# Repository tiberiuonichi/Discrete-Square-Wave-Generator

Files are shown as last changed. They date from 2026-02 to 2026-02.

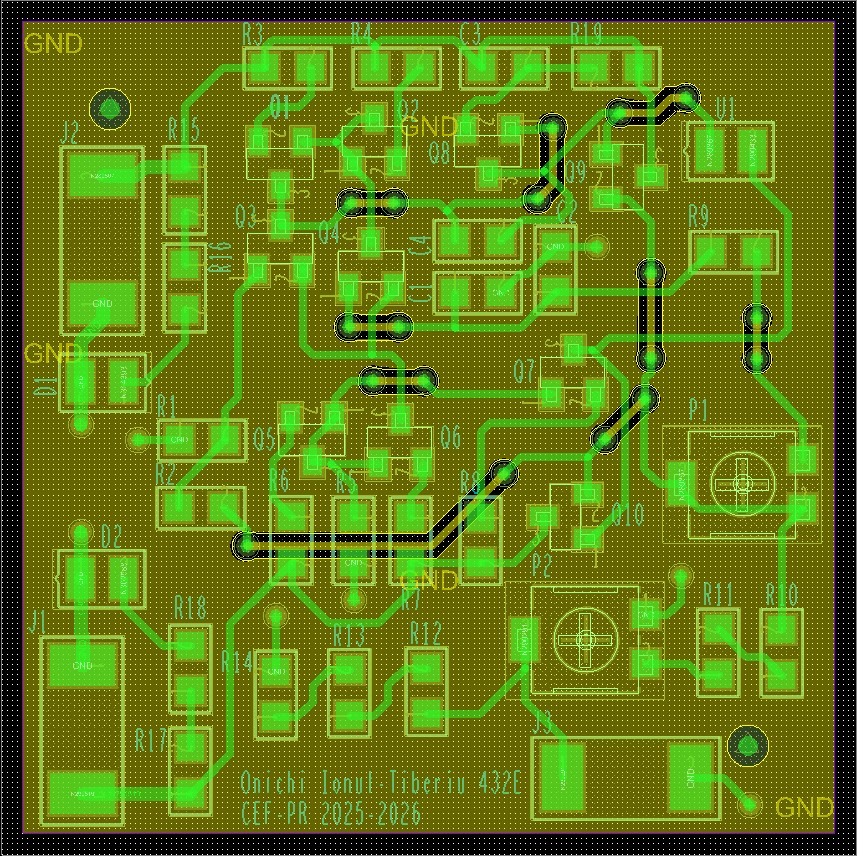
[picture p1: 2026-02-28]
Layout/LAYOUT.jpg

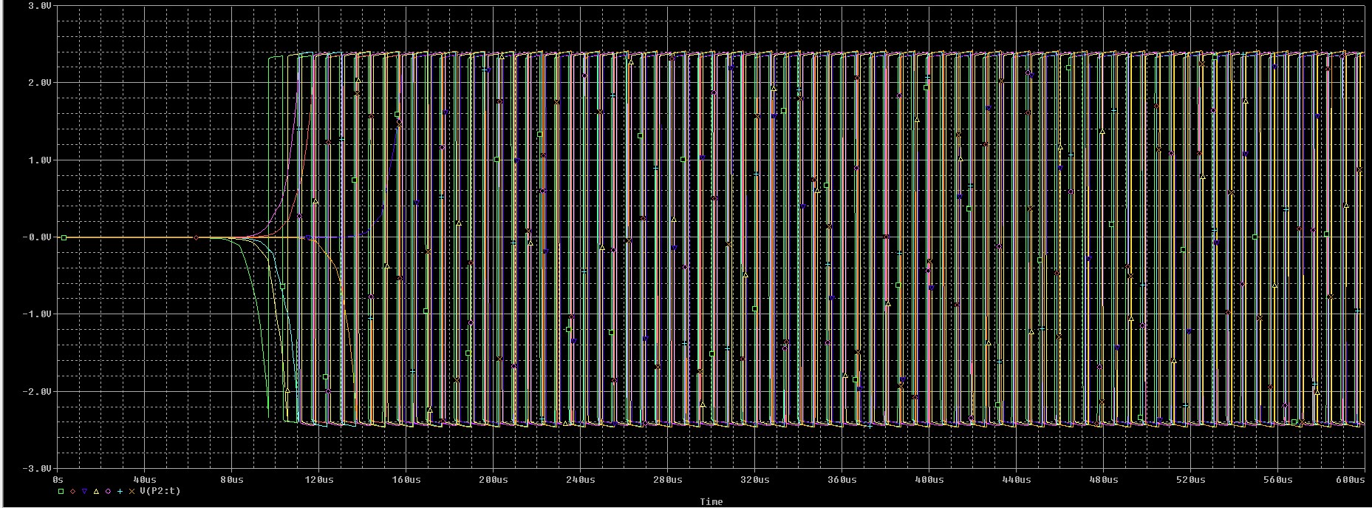
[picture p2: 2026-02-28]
Simulation/Thermal_Analysis_Sweep.jpg

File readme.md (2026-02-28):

# Discrete Transistor-Level Square Wave Generator

## Project Description
This project focuses on the design, simulation, and physical layout of a relaxation oscillator configured as a square wave generator. The core of the circuit is a Schmitt Trigger implemented through a custom-designed Operational Amplifier (Op-Amp) built entirely from discrete bipolar junction transistors (BJT). 

The implementation demonstrates a deep understanding of analog integrated circuit architecture, featuring a multi-stage amplifier design rather than relying on off-the-shelf integrated circuits. The project was developed using the Cadence OrCAD suite, including Capture for schematics, PSpice for analog analysis, and PCB Editor for the physical board design.

The design includes a complete manufacturing package (Drill Charts, Solder Mask, and Silk Screen layers) optimized for SMD assembly.

## Technical Specifications
- Topology: Relaxation Oscillator using a Discrete Op-Amp Schmitt Trigger
- Frequency Range: Adjustable from 38 kHz to 76 kHz
- Output Voltage (Vpp): 0 V to 4.75 V
- Load Impedance (RL): 19 kΩ
- Power Supply: Dual Rail ±9V DC
- Technology: Surface Mount Devices (SMD) and Through-Hole (THT) components

## Circuit Architecture
The discrete operational amplifier is composed of several fundamental stages:
1. Input Stage: Differential pair utilizing Q3 and Q4 (QBC846B) with an active load current mirror (Q1, Q2) to maximize open-loop gain and CMRR.
2. Intermediate Gain Stage: High-gain common emitter amplifier (Q8).
3. Output Stage: Complementary push-pull configuration (Q9, Q10) providing low output impedance and sufficient current drive for the feedback network.
4. Bias Circuitry: Transistor-based current sources (Q5, Q6) to ensure stable operating points across the entire operating range.

## Simulation and Performance Analysis
Extensive PSpice simulations were performed to validate the design across various conditions:
- Transient Analysis: Verification of the RC time constants and the switching thresholds.
- Power Analysis: Calculation of static and dynamic power dissipation to ensure thermal stability (Power_Dissipation_Map).
- Parametric Sweeps: Evaluation of the output frequency and amplitude stability relative to component tolerances.
- Bias Point Analysis: Validation of the DC operating points for all discrete stages (DC_Voltage_Bias_Points and DC_Current_Bias_Points).

## Project Structure
- /Design_Files: OrCAD Capture source files (.DSN, .OPJ).
- /Simulation: PSpice simulation profiles, waveforms, and analysis results.
- /Layout: PCB design files including the board file (.BRD) and manufacturing data.
- /BOM: Detailed Bill of Materials including manufacturer part numbers.
- /Docs: Technical reports, block diagrams, and manufacturing tables.
- /Datasheets: Technical specifications for the discrete components used in the design.

## Visual Documentation
The following results were captured during the PSpice simulation phase:
- Output Waveforms: [Maximum Peak-to-Peak Voltage](Simulation/Maximum_Peak-to-Peak_Voltage.jpg), [Minimum Peak-to-Peak Voltage](Simulation/Minimum_Peak-to-Peak_Voltage.jpg).
- Analysis: [Thermal_Analysis_Sweep](Simulation/Thermal_Analysis_Sweep.jpg), [Power Dissipation Map](Simulation/Power_Dissipation_Map.jpg).
- DC Verification: [Voltage Bias Points](Simulation/DC_Voltage_Bias_Points.jpg), [Current Bias Points](Simulation/DC_Current_Bias_Points.jpg).

## Documentation
The detailed technical report, including analytical calculations for the Op-Amp stages and PSpice simulation results, is available in the following document:
- [Technical_Report_RO.pdf](Docs/Technical_Report_RO.pdf) (Language: Romanian)

---
- **Author:** Onichi Ionut-Tiberiu
- **Tools:** OrCAD, GitHub Desktop.

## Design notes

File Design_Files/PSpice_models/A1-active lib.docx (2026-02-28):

77 | 4148 | (LINK) (http://www.tme.eu/ro/details/1n4148-0805/diode-universale-smd/dc-components/cd4148ws0805c/) | 1N4148-0805
79 | 2.7V | (LINK) (http://www.tme.eu/ro/details/bzx84c2v7/diode-zener-smd/on-semiconductor/bzx84c2v7lt1g/) | BZX84C2V7
80 | 5.1V | (LINK) (http://www.tme.eu/ro/details/bzx84c5v1/diode-zener-smd/nxp/bzx84-c5v1215/) | BZX84C5V1
81 | 5.6V | (LINK) (http://www.tme.eu/ro/details/bzx84c5v6/diode-zener-smd/nxp/bzx84-c5v6215/) | BZX84C5V6
82 | 6.2V | (LINK) (http://www.tme.eu/ro/details/bzx84c6v2/diode-zener-smd/nxp/bzx84-c6v2215/) | BZX84C6V2
83 | 6.8V | (LINK) (http://www.tme.eu/ro/details/bzx84c6v8/diode-zener-smd/nxp/bzx84-c6v8215/) | BZX84C6V8
84 | 8.2V | (LINK) (http://www.tme.eu/ro/details/bzx84c8v2/diode-zener-smd/nxp/bzx84-c8v2215/) | BZX84C8V2
85 | 10V | (LINK) (http://www.tme.eu/ro/details/bzx84c10/diode-zener-smd/nxp/bzx84-c10215/) | BZX84C10
86 | PNP | (LINK) (http://www.tme.eu/ro/details/bc856b.215/tranzistori-smd-pnp/nxp/) | BC856B
87 | NPN | (LINK) (http://www.tme.eu/ro/details/bc846b.215/tranzistori-smd-npn/nxp/) | BC846B
89 | N-JFET | (LINK) (http://www.tme.eu/ro/details/mmbfj309lt1g/tranzistori-canal-n-smd/on-semiconductor/) | MMBFJ309LT1G
90 | P-JFET | (LINK) (http://www.tme.eu/ro/details/mmbfj177lt1g/tranzistori-canal-p-smd/on-semiconductor/) | MMBFJ177LT1G
91 | NPN | (LINK) (http://www.tme.eu/ro/details/bc817-25-dio/tranzistori-smd-npn/diotec-semiconductor/bc817-25/) | BC817-25-DIO
93 | PNP | (LINK) (http://www.tme.eu/ro/details/bc807-25-dio/tranzistori-smd-pnp/diotec-semiconductor/bc807-25/) | BC807-25-DIO
94 | NPN | (LINK) (http://www.tme.eu/ro/details/mjd31cg/tranzistori-smd-npn/on-semiconductor/) | MJD31CG
96 | PNP | (LINK) (http://www.tme.eu/ro/details/mjd32cg/tranzistori-smd-pnp/on-semiconductor/) | MJD32CG
97 | Nmos | (LINK) (http://www.tme.eu/ro/details/irfr120npbf/tranzistori-canal-n-smd/international-rectifier/) | IRFR120NPBF

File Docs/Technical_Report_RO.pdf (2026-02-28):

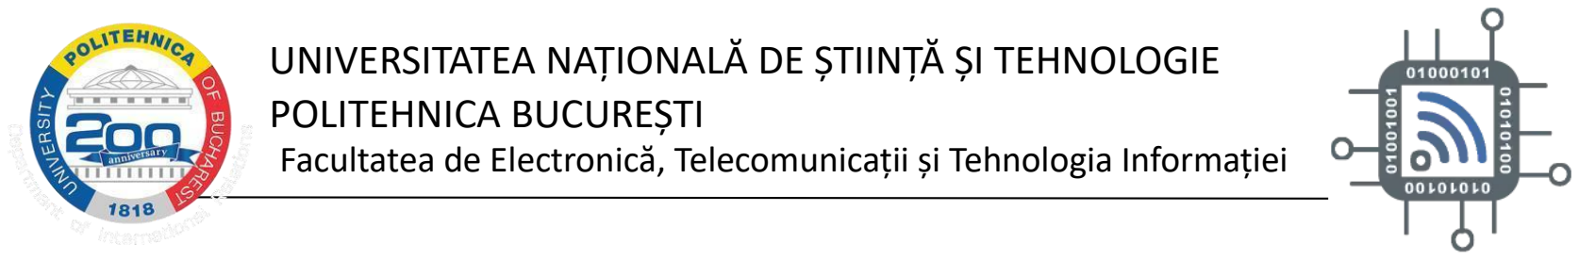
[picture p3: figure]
POLITEHNICA BUCUREȘTI

## Proiect 1 – Dispozitive și circuite electronice

## Generator de semnal dreptunghiular

### Student: Onichi Ionuț-Tiberiu Grupa: 432E

### Profesori coordonatori: Conf. Dr. Ing. Drăghici Florin Ș.l. Dr. Ing. Pantazică Mihaela

## UNIVERSITATEA NAȚIONALĂ DE ȘTIINȚĂ ȘI TEHNOLOGIE

### Facultatea de Electronică, Telecomunicații și Tehnologia Informației

# Cuprins

# 1. Date inițiale de proiectare

## 1.1. Tema proiectului

### Să se proiecteze și realizeze un generator de semnal dreptunghiular cu următoarele caracteristici:

- Frecvența de oscilație, f0, reglabilă în intervalul 38-76 KHz;
- Factor de umplere: 0.5;
- Sarcina la ieșire, RL: 19kΩ;
- Valoarea (vârf la vârf) a oscilației la ieșire, Vo, reglabilă în intervalul 0-4.75V;
- Semnalul la ieșire nu are componentă continuă;

### - Domeniul temperaturilor de funcționare: 0° - 70°C (verificabil prin testare în

temperatură);
- Semnalizarea prezenței tensiunilor de intrare/ieșire cu o diodă de tip LED.

## 1.2. Schema bloc a montajului electric

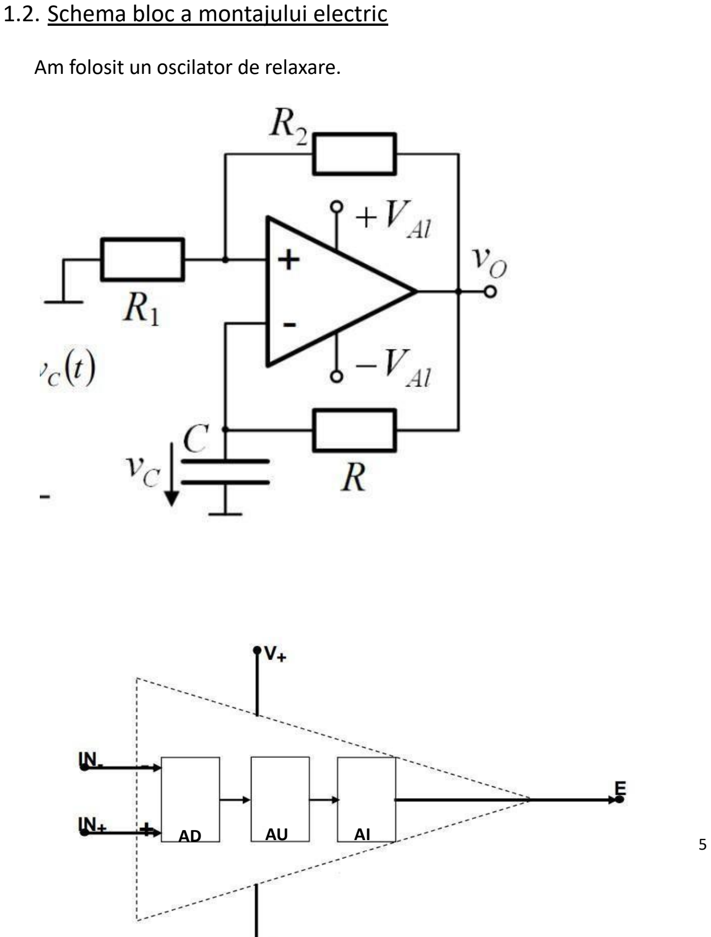
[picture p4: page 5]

AD | AU | AI

Am folosit un oscilator de relaxare.

## 1.3. Schema electrică a montajului electric

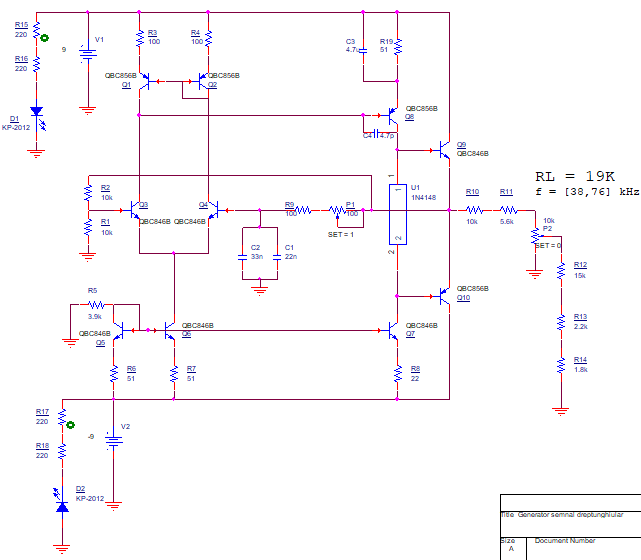
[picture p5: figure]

# 2. Conținut tehnic/științific al proiectului

## 2.1. Descrierea funcțională a circuitului

### Am construit un oscilator de relaxare dintr-un comparator inversor cu histerezis și

o rețea RC pe intrarea inversoare.

### Intrarea neinversoare este conectată la divizorul de tensiune format din R1 și R2, prin intermediul căruia de aplică o parte din semnalul de la ieșire și prin care se fixează

tensiunile de prag de histerezis.

Gruparea formată din C1, C2, R9 și P1 setează frecvența de oscilație.

### Amplificatorul operațional folosit este unul standard, format din 3 etaje de amplificare:

### - etaj de amplificare diferențială

### - etaj de amplificare în tensiune

- etaj de amplificare în curent.
Am folosit două surse de alimentare de ±9V.

### 2.1.1. Etajul diferențial

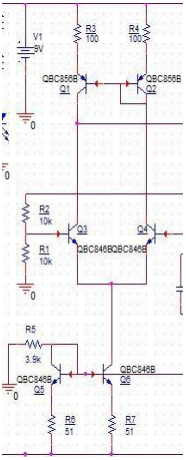
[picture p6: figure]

### Etajul are rolul de a realiza conversia dintre o tensiune de

intrare și o mărime de ieșire exprimată drept curent,

### comportându-se ca un bloc de transconductanță. Cu ajutorul impedanței de intrare foarte mari, acesta poate face cu legătura între sursa de semnal și etajele următoare ale

amplificatorului operațional.

### Structura principală este alcătuită din tranzistoarele NPN Q3 și Q4, tip BC846B, care primesc direct semnalele aplicate la

intrările amplificatorului operațional.

### Pentru a crește câștigul, a îmbunătăți stabilitatea funcționării și a limita nivelul de zgomot, sunt integrate două subetaje

suplimentare: o oglindă de curent și o sursă de curent.

### Tranzistoarele PNP Q1 și Q2, de tip BC856B, sunt utilizate pentru a asigura egalitatea curenților de colector ai

tranzistoarelor care formează etajul diferențial principal.

### Polarizarea elementelor active este furnizată de o sursă de curent realizată cu Q5, Q6 și rezistorul R9. Această configurație generează un curent de referință de 2.11 mA, necesar pentru

formarea unui semnal dreptunghiular bine proporționat.

### 2.1.2. Etajul de amplificare în tensiune

### În acest caz am utilizat un etaj de transimpedanță, conceput să

convertească curentul de la intrare într-o tensiune ridicată la ieșire.

### Datorită amplificării mari în regim de buclă deschisă, am folosit o reacție negativă pentru a stabiliza și ajusta tensiunea la valoarea

cerută în specificațiile inițiale.

### În acest etaj intervin două condensatoare cu roluri specifice:

### Condensatorul de 4.7 pF funcționează ca un condensator Miller, fiind responsabil pentru compensarea în frecvență. Reduce câștigul la

frecvențe înalte și asigură stabilitatea buclei de reacție.

Condensatorul de 4.7 µF are rol de filtrare și decuplare a alimentării.

### Acesta stabilizează tensiunea din nodul respective și reduce zgomotul provenit din alimentare, contribuind la funcționarea stabilă a sursei

de curent.

### Amplificarea propriu-zisă este realizată de tranzistorul PNP Q7, model BC856B, configurat în emitor comun, ceea ce îi conferă un câștig ridicat. Acesta asigură reglarea tensiunii la nivelul dorit și are ca element de sarcină o sursă de curent bazată pe tranzistorul

Q8.

### Sursa de curent stabilește curentul care alimentează etajul final, determinând

astfel funcționarea corectă a întregului ansamblu.

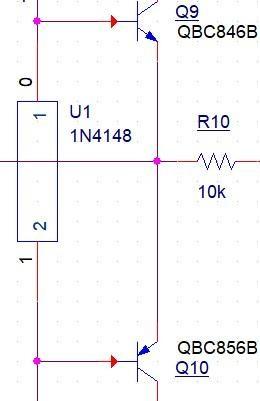
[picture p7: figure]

### 2.1.3. Etajul de amplificare în curent

### Acest etaj are o amplificare unitară a tensiunii stabilite în etajul anterior, motiv pentru care este

utilizată o conexiune de tip colector comun. Tranzistoarele vor disipa o putere semnificativă, datorită curentului care va trece și prin sarcină.

### Configurate push-pull, cele două tranzistoare funcționează ca un etaj final de clasă B: Q9 gestionează alternanțele pozitive, iar Q10 pe cele

negative.

### Dioda 1N4148 asigură polarizarea corectă bază– emitor pentru ambele tranzistoare, reducând zona

moartă și distorsiunile.

### 2.1.4. LED

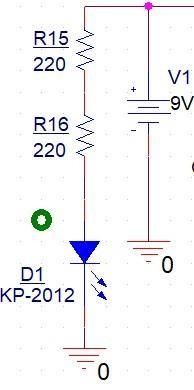
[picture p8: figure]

### Conform cerințelor am semnalizat tensiunile de intrare/iesire în circuit printr-un led de tip KP2012SRC-PRV, în serie cu rezistența R15/ R17 și

R16/R18.

### Luând în considerare puterea maximă admisă pe rezistente (125mW), pe LED(100mW) și valoarea tensiunii de funcționare uzuală pentru acesta (aproximativ 2.2V), precum și curentul necesar pentru aprindere [1 – 30 mA], am ales valoarea

de 220Ω pentru rezistențe.

## 2.2. Calcul de dimensionare

### 2.2.1. Frecvența de oscilație & factorul de umplere

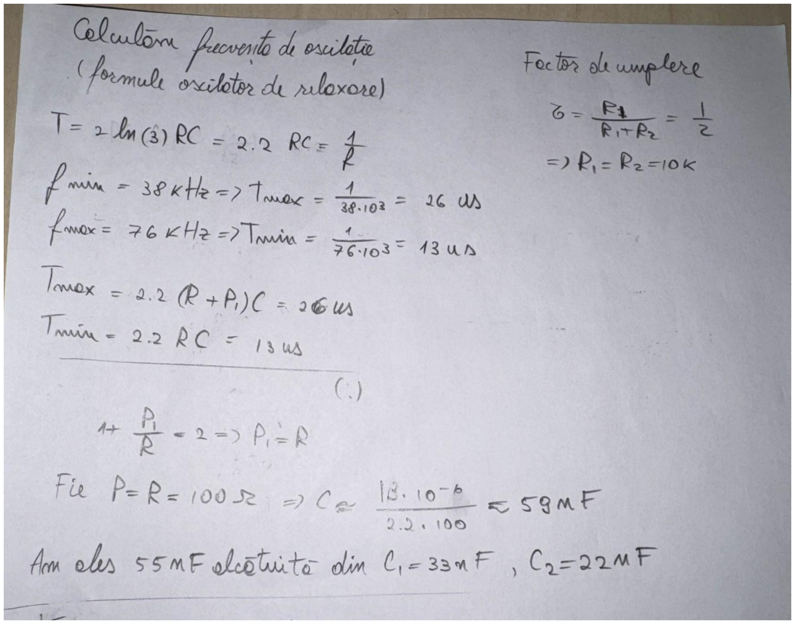
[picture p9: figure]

### 2.2.2. Tensiunea vârf la vârf

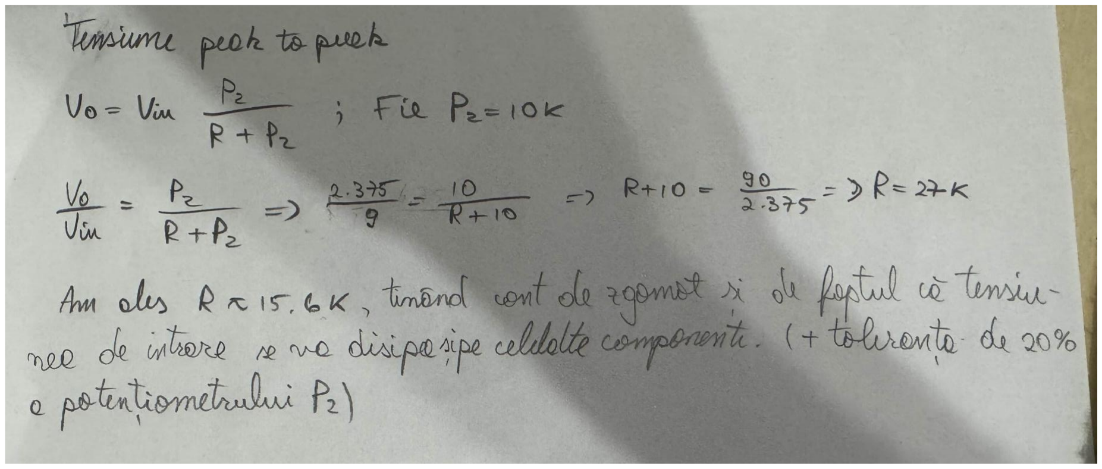
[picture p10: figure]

## 2.3. Punctul static de funcționare

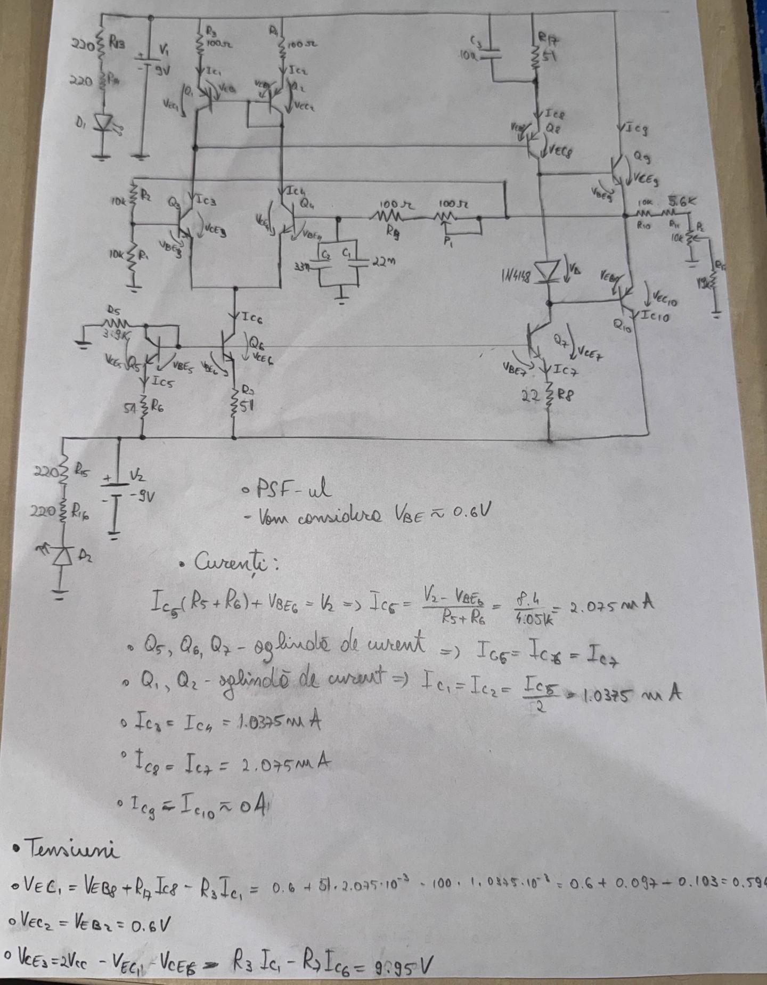
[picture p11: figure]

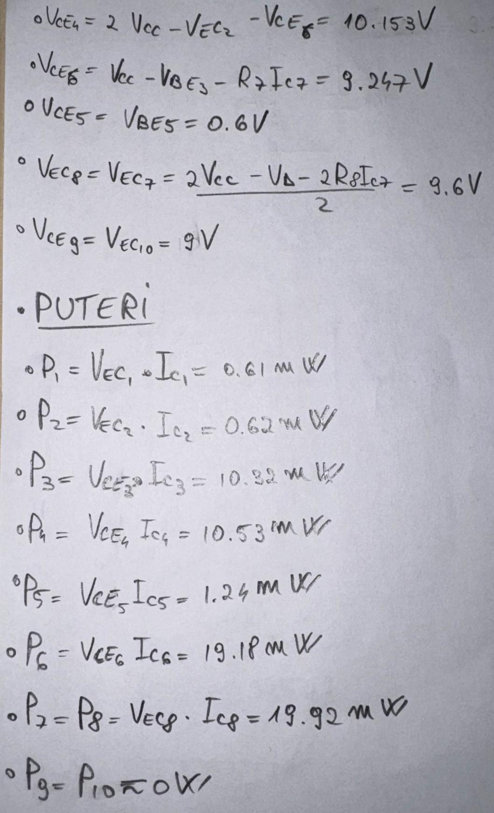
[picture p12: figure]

# 3. Simularea montajului electric

## 3.1. Curenți

### Verificând foile de catalog ale componentelor, acestea merg în regulă la curenții

obținuți.

## 3.2. Tensiuni

### Verificând foile de catalog ale componentelor, acestea merg în regulă pentru

tensiunile obținute.

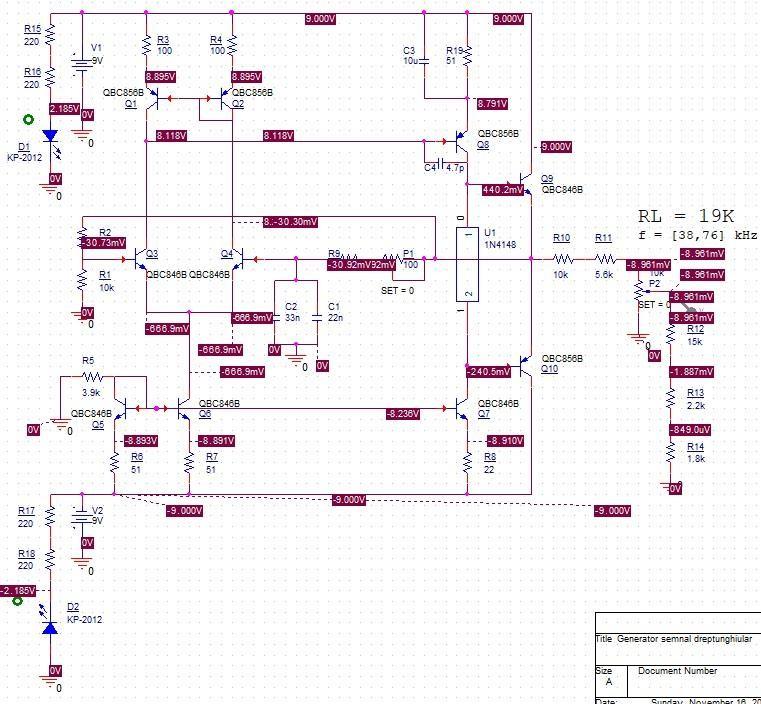
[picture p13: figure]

## 3.3. Puteri

### De asemenea, și puterile se încadrează în parametrii normali de funcționare a

componentelor.

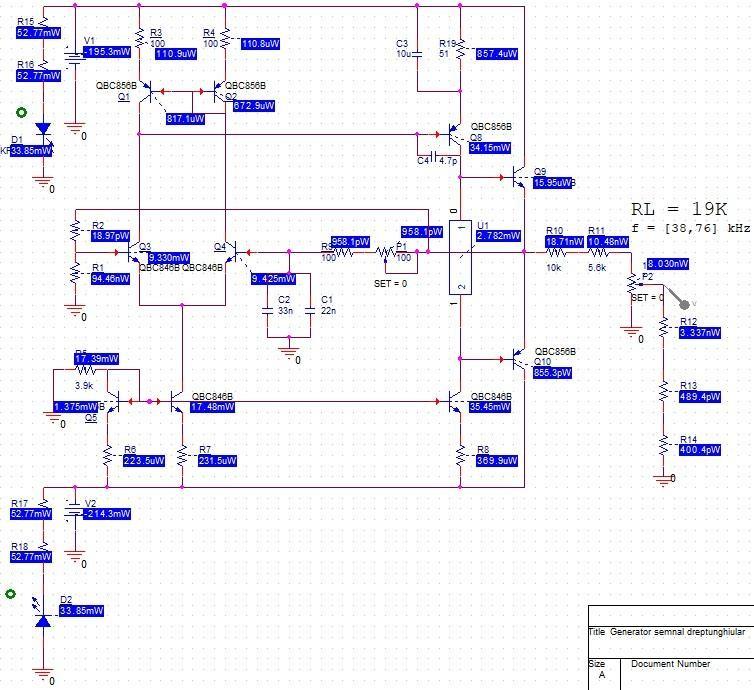
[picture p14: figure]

3.4. P1 = 0, P2 = 0Ω.

### Pentru aceste valori se obțin:

- fmin= 38.77kHz;
- VPP= 4.78V;
- Componenta continuă este neglijabilă.

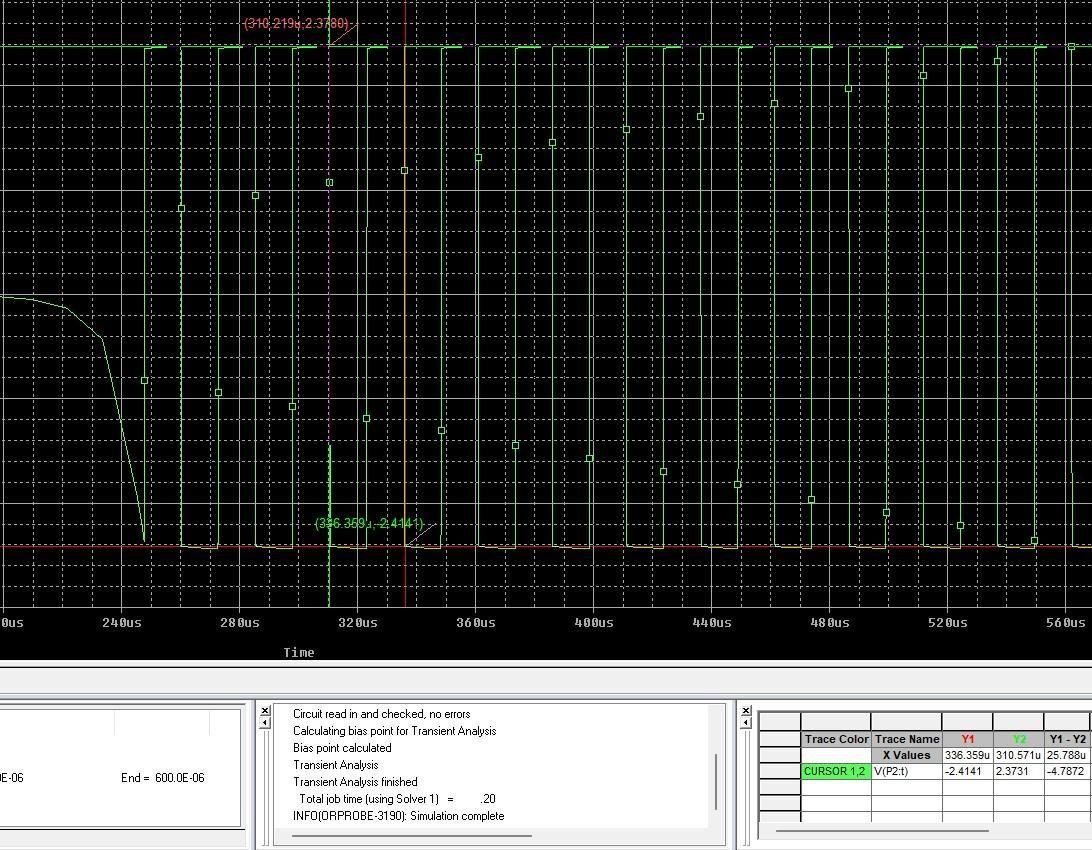
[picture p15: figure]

3.5. P1 = 100Ω, P2 = 0Ω.

### Pentru aceste valori se obțin:

- fmax= 77.5kHz;
- VPP= 4.74V;
- Componenta continuă este neglijabilă.

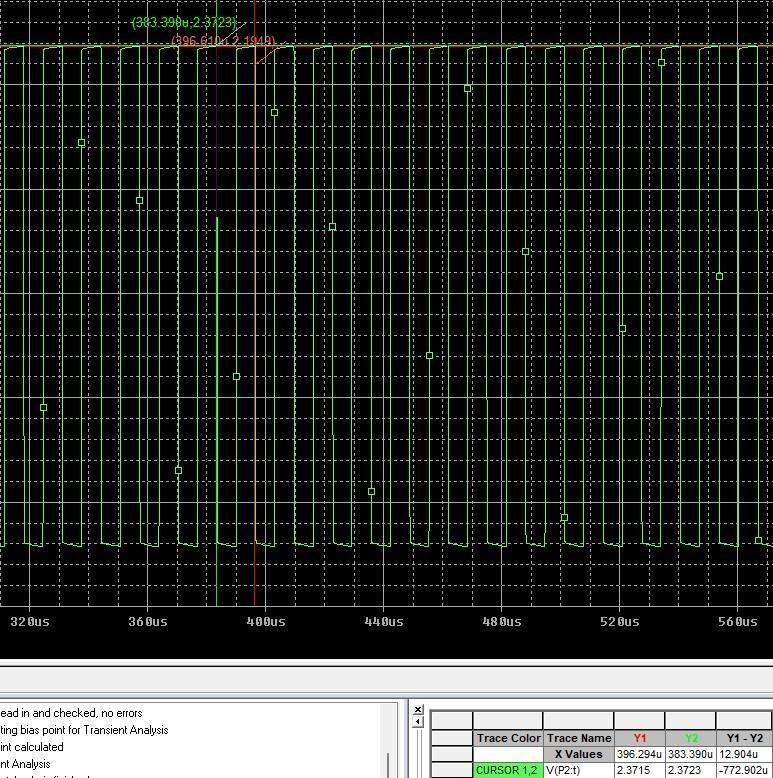
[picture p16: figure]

## 3.6. P1=100Ω & P1=0, P2=10k

### Pentru aceste valori se obțin:

- fmax= 77.6kHz & fmin= 38.8kHz;
- VPP= 631nV;

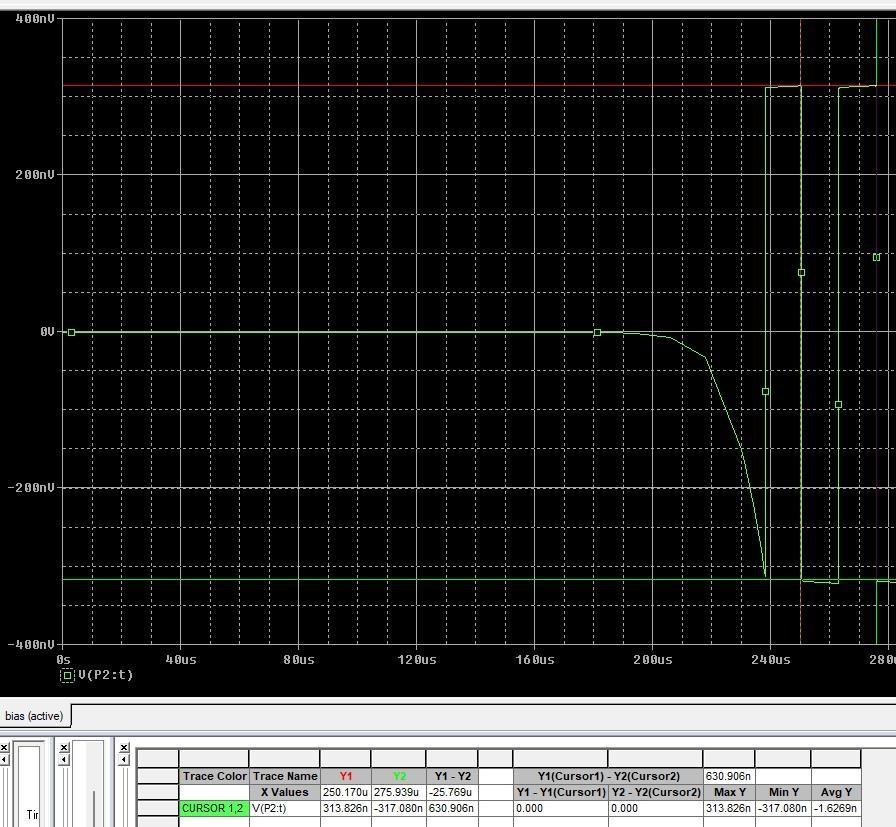
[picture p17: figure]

## 3.7. Temperatură

### Am simulat funcționarea circuitului la -20°, 0°, 25°, 50°, 75°, 100°, 120°C, toate

componentele funcționând normal în tot intervalul de temperatură.

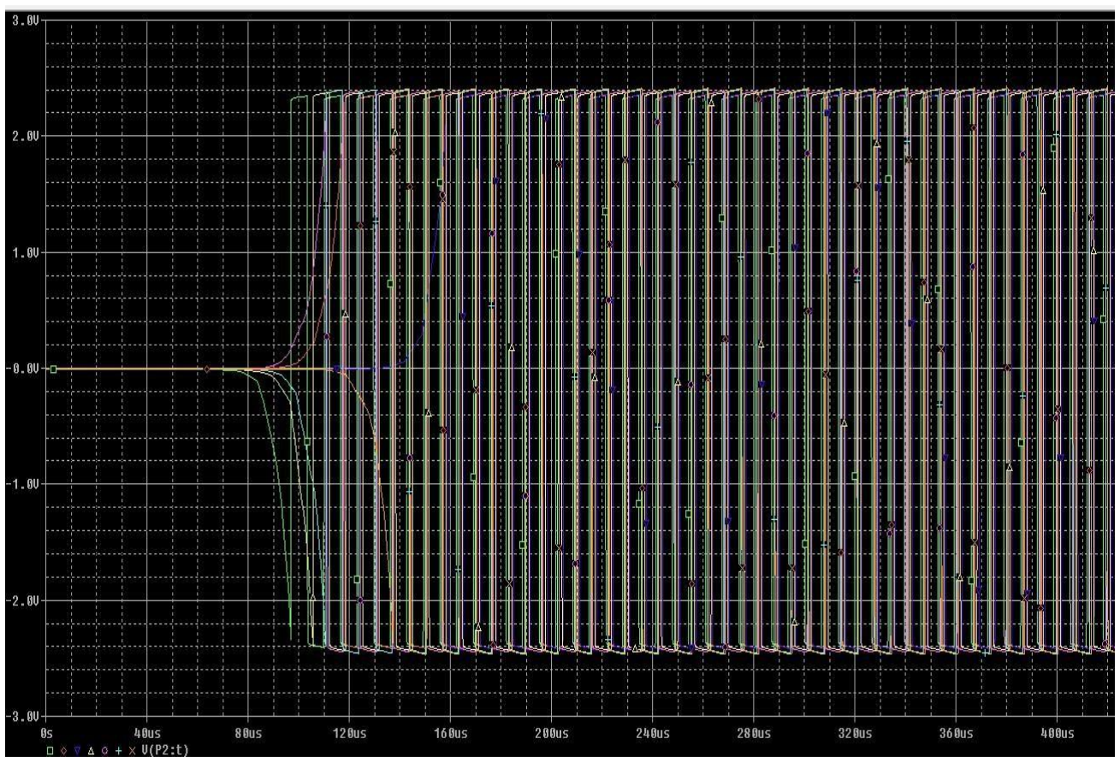
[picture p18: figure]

# 4.Layout

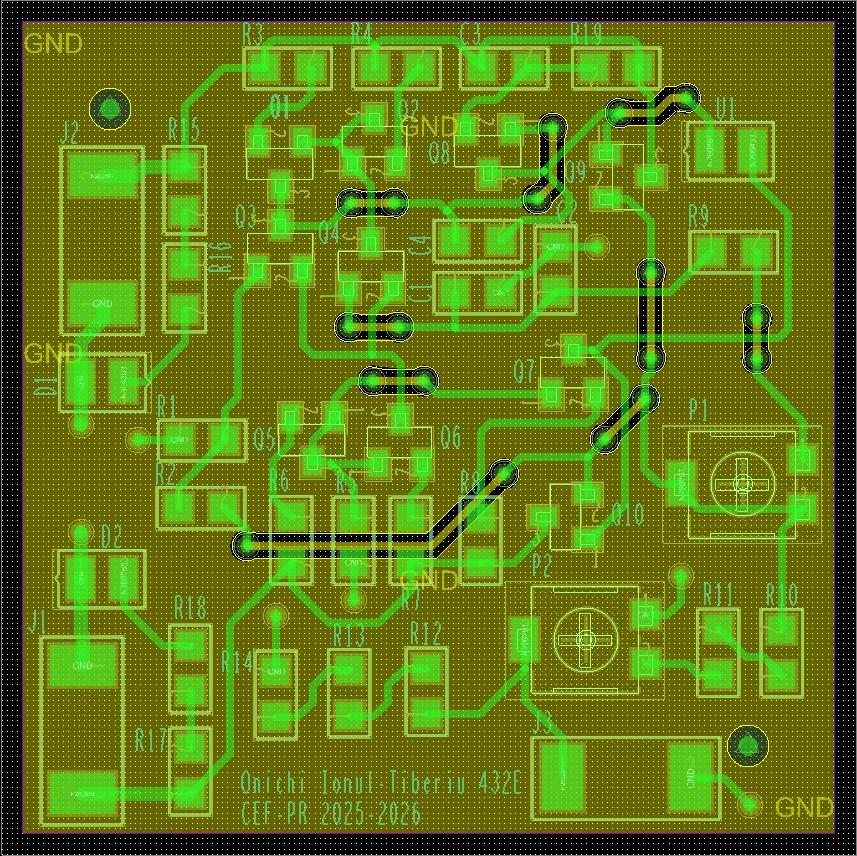
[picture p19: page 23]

### 4.1. PCB DESIGN

## 4.2. BOARD OUTLINE

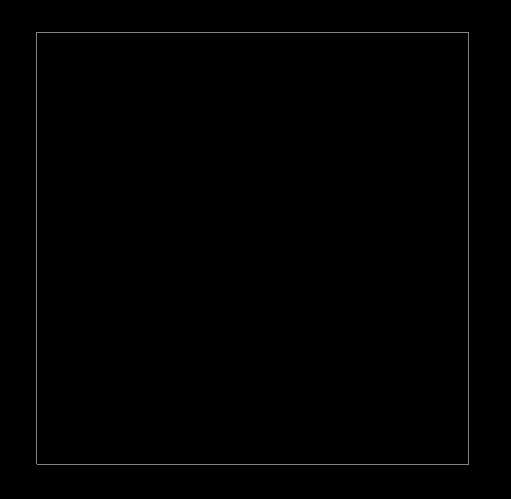
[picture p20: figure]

## 4.3. BOTTOM

## 4.4. FABRICATION

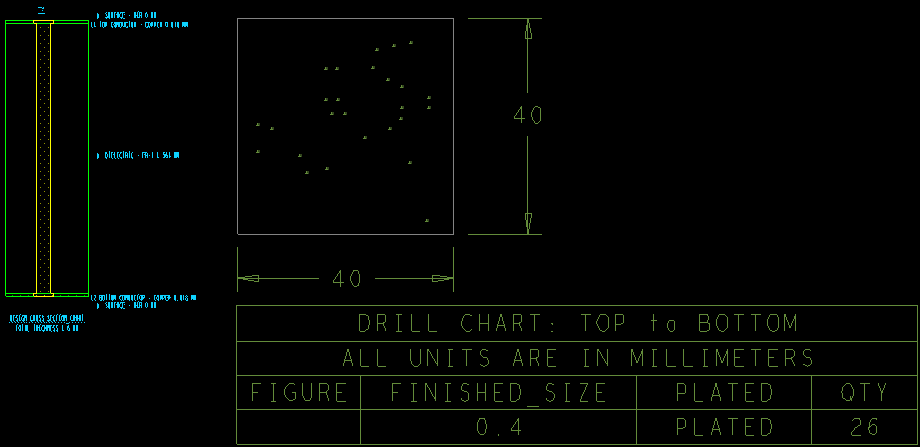
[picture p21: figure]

## 4.5. SOLDERMASK BOTTOM

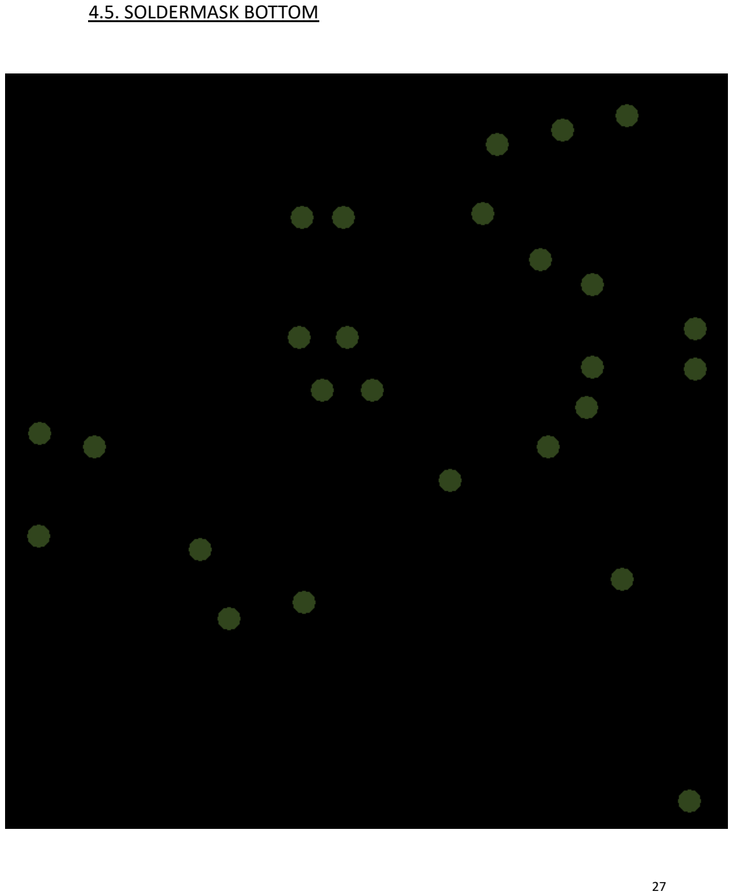
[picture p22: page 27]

## 4.6. SOLDERMASK TOP

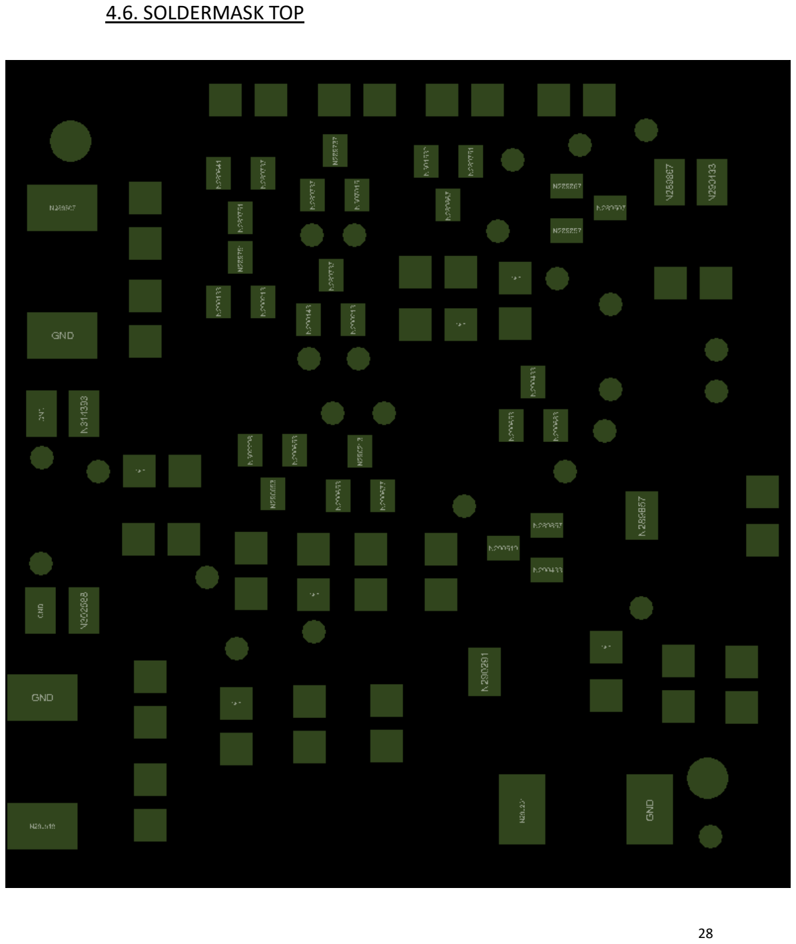
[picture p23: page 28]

## 4.7. SOLDERPASTE TOP

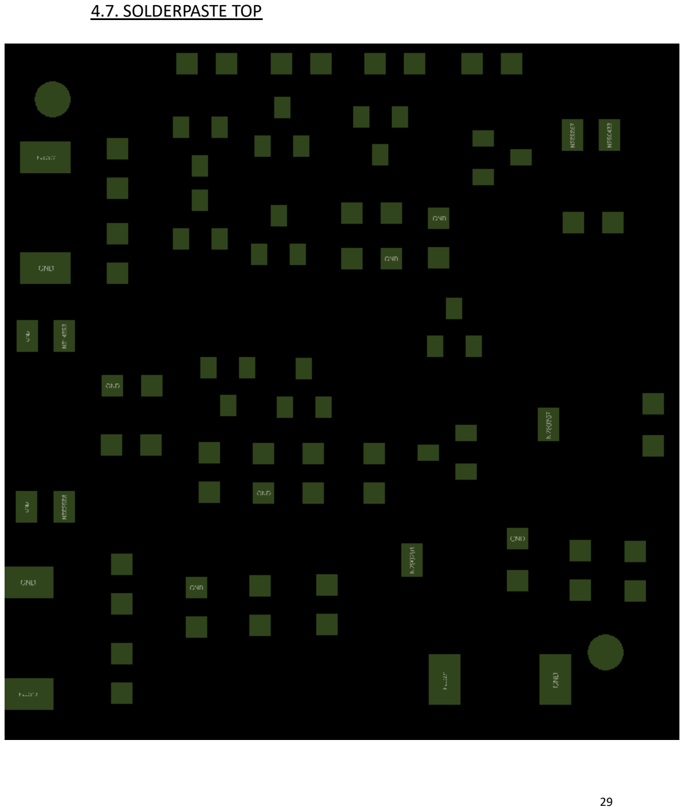
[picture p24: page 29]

## 4.8. SILKSCREEN TOP

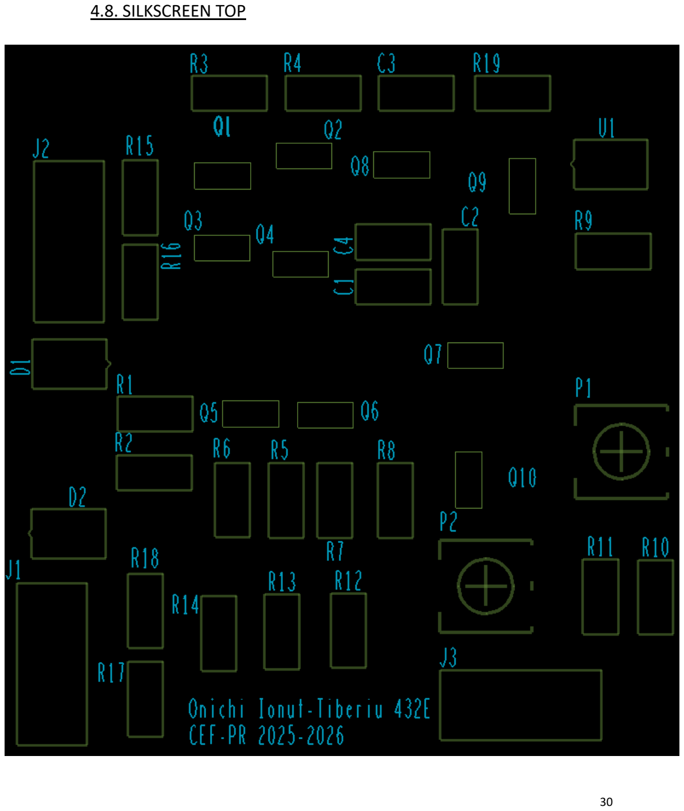
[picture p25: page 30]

## 4.9. LAYER TOP

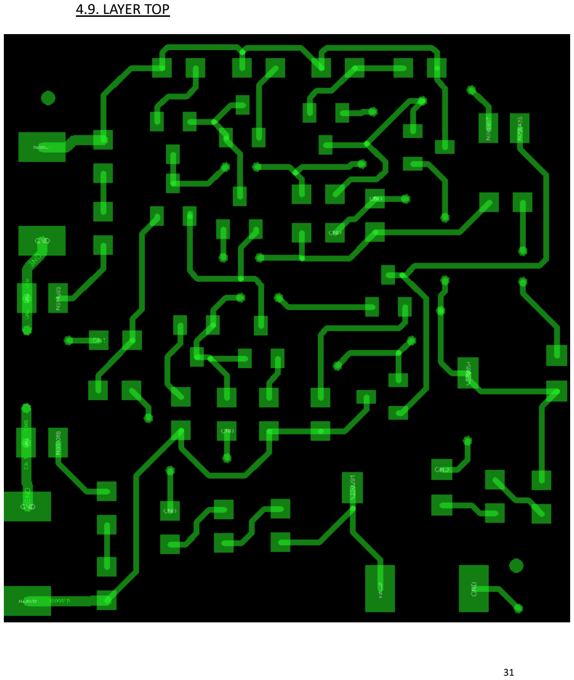
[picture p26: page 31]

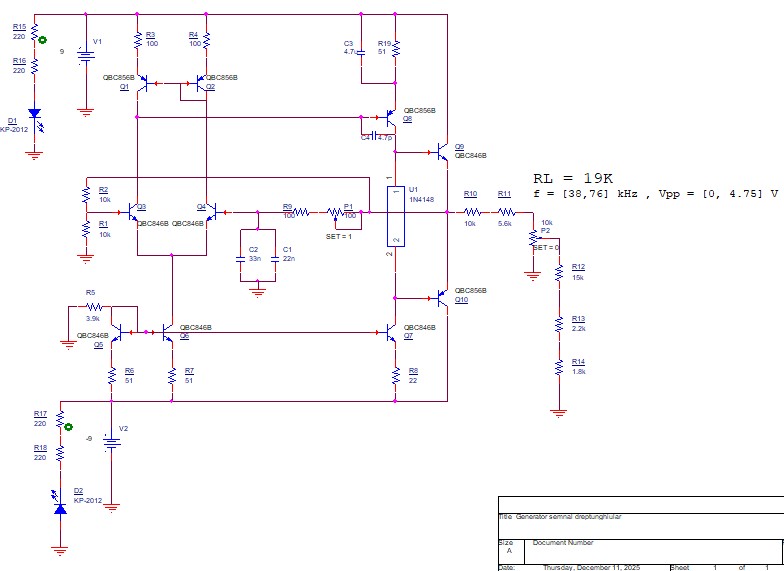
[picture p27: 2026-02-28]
Design_Files/Electric_Diagram.jpg

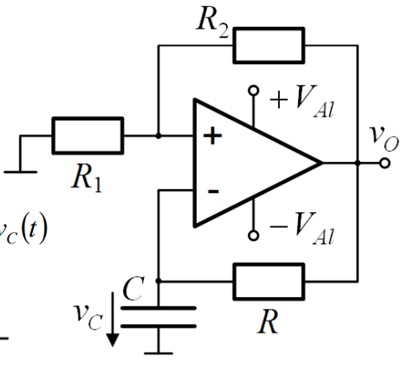
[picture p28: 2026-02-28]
Design_Files/Block_Diagram.jpg

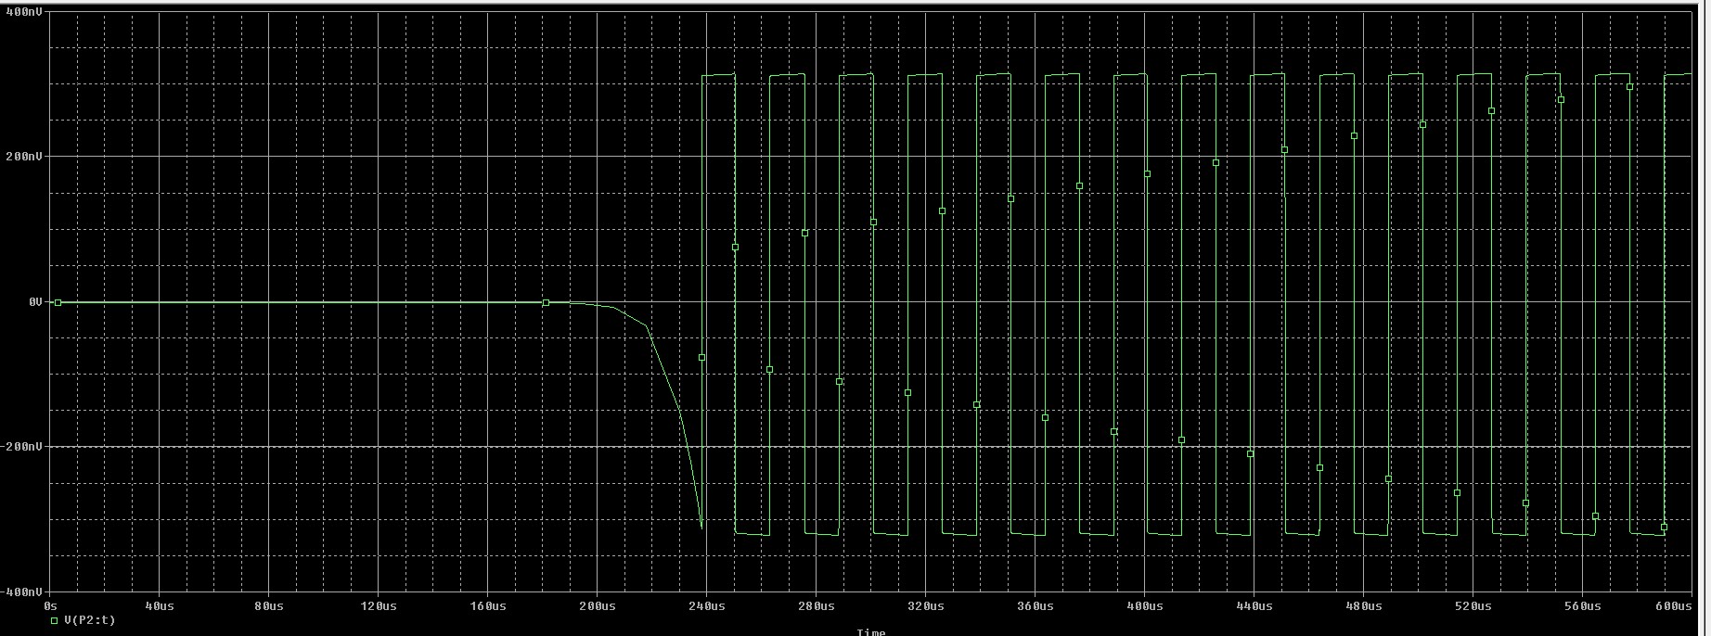
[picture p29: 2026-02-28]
Simulation/Minimum_Peak-to-Peak_Voltage.jpg

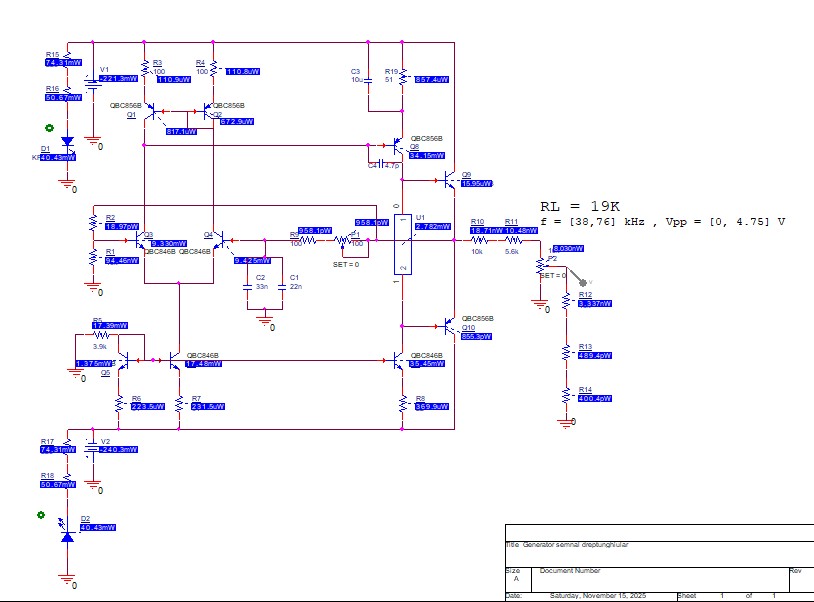
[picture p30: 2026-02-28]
Simulation/Power_Dissipation_Analysis.jpg

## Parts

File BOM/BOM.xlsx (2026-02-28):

Item | Quantity | Reference | Part
______________________________________________
1 | 1 | C1 | 22n
2 | 1 | C2 | 33n
3 | 1 | C3 | 4.7u
4 | 1 | C4 | 4.7p
5 | 2 | D1,D2 | KP-2012
6 | 3 | J1,J2,J3 | CON2
7 | 4 | P1,R3,R4,R9 | 100
8 | 4 | R1,R2,P2,R10 | 10k
9 | 4 | Q1,Q2,Q8,Q10 | QBC856B
10 | 6 | Q3,Q4,Q5,Q6,Q7,Q9 | QBC846B
11 | 1 | R5 | 3.9k
12 | 3 | R6,R7,R19 | 51
13 | 1 | R8 | 22
14 | 1 | R11 | 5.6k
15 | 1 | R12 | 15k
16 | 1 | R13 | 2.2k
17 | 1 | R14 | 1.8k
18 | 4 | R15,R16,R17,R18 | 220
19 | 1 | U1 | 1N4148

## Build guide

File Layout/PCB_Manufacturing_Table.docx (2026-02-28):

General info document for PCB manufacturing
No. | Item Name | File Name | | | | | | Info / Remarks / Notes
| BOARD
1 | Board Name / Number | PROIECT1_CEF.brd | | | | | | -
2 | Revision Date | 13 December 2025 | | | | | | -
3 | Board Size | 40 x 40 mm² | | | | | | -
4 | Board Quantity | 1 | | | | | | -
5 | Material / Dielectric Type | FR4 | | | | | | -
6 | Board Thickness | 1.6 mm | | | | | | -
7 | Copper Thickness | 18 μm | | | | | | -
| LAYERS
8 | Number of Electrical Layers | 2 | | | | | | -
9 | Copper Layer TOP | TOP.art | | | | | | -
10 | Copper Layer BOTTOM | BOTTOM.art | | | | | | -
11 | Copper GND Plane | - | | | | | | -
12 | Copper PWR Plane | - | | | | | | -
13 | Copper INNER 1 | - | | | | | | -
14 | Copper INNER 2 | - | | | | | | -
15 | Solder Mask TOP | SMTOP.art | | | | | | -
16 | Solder Mask BOTTOM | SMBOT.art | | | | | | -
17 | Solder Paste TOP | SPTOP.art | | | | | | -
18 | Solder Paste BOTTOM | - | | | | | | -
19 | Peelable Mask TOP | - | | | | | | -
20 | Peelable Mask BOTTOM | - | | | | | | -
21 | Silk Screen TOP | SSTOP.art | | | | | | -
22 | Silk Screen BOTTOM | - | | | | | | -
23 | Board Outline | BO.art | | | | | | -
24 | Fabrication Drawing | FAB.art | | | | | | -
| MILLING & DRILLING
25 | Mill Drawing | - | | | | | | -
26 | Drill Drawing | DRILL.drl | | | | | | -
27 | N.C. Drill (for both PH & NPH) | - | | | | | | -
28 | N.C. Drill / Plated Holes (PH) | - | | | | | | -
29 | N.C. Drill / Non-Plated Holes (PH) | - | | | | | | -
| FINISHING
30 | Panelisation | - | | | | | | -
31 | Electrical Test | - | | | | | | -
32 | Copper Finishing | x | HASL | | OSP | | | ENIG
33 | Board Outline Machining | | Routing | | Milling | | x | V-Cutting
34 | Final remarks | - | | | | -

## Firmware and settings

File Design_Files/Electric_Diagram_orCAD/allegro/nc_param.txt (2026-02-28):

INTEGER-PLACES         2
DECIMAL-PLACES         5
X-OFFSET               0.000000
Y-OFFSET               0.000000
FEEDRATE               1
COORDINATES            ABSOLUTE
OUTPUT-UNITS           METRIC
TOOL-ORDER             INCREASING
REPEAT-CODES           YES
SUPPRESS-LEAD-ZEROES   YES
SUPPRESS-TRAIL-ZEROES  NO
SUPPRESS-EQUAL         NO
TOOL-SELECT            YES
OPTIMIZE_DRILLING      NO
ENHANCED_EXCELLON      YES
HEADER                 none
LEADER                 12
CODE                   ASCII
SEPARATE               NO
SEPARATE-ROUTING       NO
DRILLING               LAYER-PAIR
BACKDRILL              NO
CAVITY                 NO
COUNTER                NO
TOLERANCE_DRILL        YES
TOLERANCE_TRAVEL       YES
TOOL_SIZE              YES
ROTATION               YES
NON_STANDARD           YES
TOTAL_DRILL            NO
SEPARATE_SLOT          NO
SUPPRESS_TOLERANCE     YES
SUPPRESS_TOOLSIZE      YES
SUPPRESS_ROTATION      YES
